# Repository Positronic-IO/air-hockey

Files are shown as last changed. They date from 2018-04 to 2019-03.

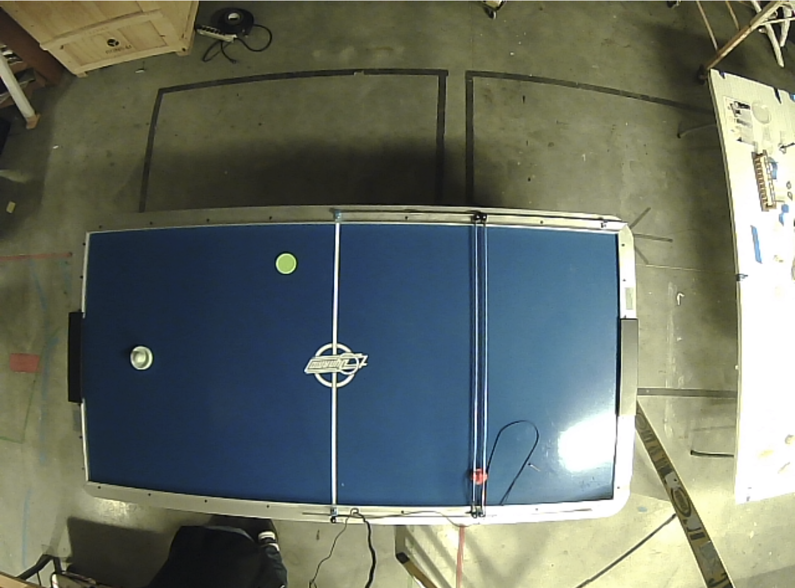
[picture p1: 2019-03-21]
notebooks/overhead-science.png

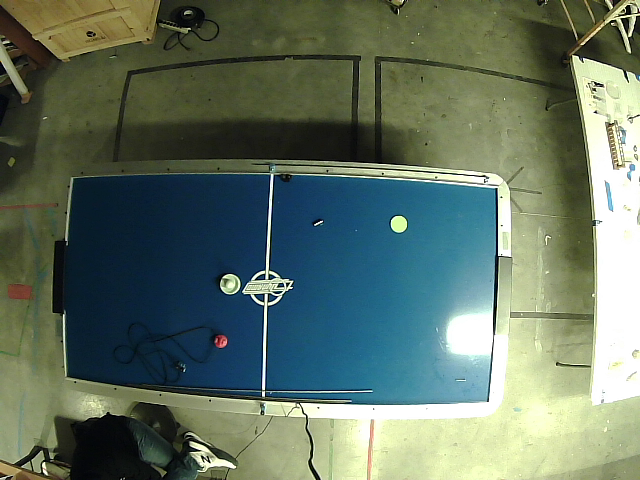
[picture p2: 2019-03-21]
notebooks/overhead-science-2.png

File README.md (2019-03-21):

# Air Hockey Vision and Robot Interface

## Introduction

In our goal to create an AI powered air hockey opponent, we have developed a vision system, state machine, and robot interface so that the robot can play in real time against a human opponent.

## Prerequisites

First, you will need to install all necessary dependencies.

### Python dependencies

Run `pip3 install pipenv`. `pipenv` is used for Python package management. 

Once downloaded, run `pipenv install`. This will create a virtual environment for our application and will install the dependencies from the `Pipfile.lock` file. If this is not present, it will default to the `Pipfile` file.

### YOLO and Darknet dependencies

We use YOLO2 and Darknet for the vision system. You will need to install `CUDA 9.0` and `cuDNN 7.0`. I would follow this [tutorial](https://medium.com/@zhanwenchen/install-cuda-and-cudnn-for-tensorflow-gpu-on-ubuntu-79306e4ac04e) to set this up on your machine.

### Install Redis

You can either install redis via Docker or `apt-get`. It is up to your preference.

## Calibration and get up and running.

There are a few steps you have to do to sync up the camera footage with the robot.

The html canvas and robot sets the origin point at the top left corner. However, the top left corner of the table in the footage is not the origin. Thus, you will need to compute the offset necessary to translate the frames up and left so that the top left corner of the table in the footage is the origin point.

It does not matter if Redis has already been started or not.

_Make sure you are in your virtual environment. Run `pipenv shell` to initiate you environment if you are not already in it._

1. Grab a image from the source where your bot will be playing. This will be used to determine its location and dimensions.
2. Run `python calibrate_offset.py --file <Your Image>`. This will grab the necessary information and publish it to redis to be used for later.
3. In `retrieve_state.py`, set your defaults. The table dimensions either user-defined. Other defaults are dependent on your table and specifications. Please play with these.
4. Run `retrieve_state.py`. This will we retrieve the state of the entire application. It will also compute where the robot should move to. All puck/bot physics or AI should be defined in the `meet_the_puck` function.
5. In the `./simulator`, edit the `index.html` canvas components `width` and `height` attributes. Set these to the table dimensions.
6. In the same directory, run `npm start` to start simulator. Open `http://localhost:3000` to see where the puck and bot is on the table.
7. Run `python yolo/table.py` to start recording the state of the game from the YOLO2/Darknet neural net.

#### Author

Positronic Ai - Visit us at our [website](https://positronic.ai)!

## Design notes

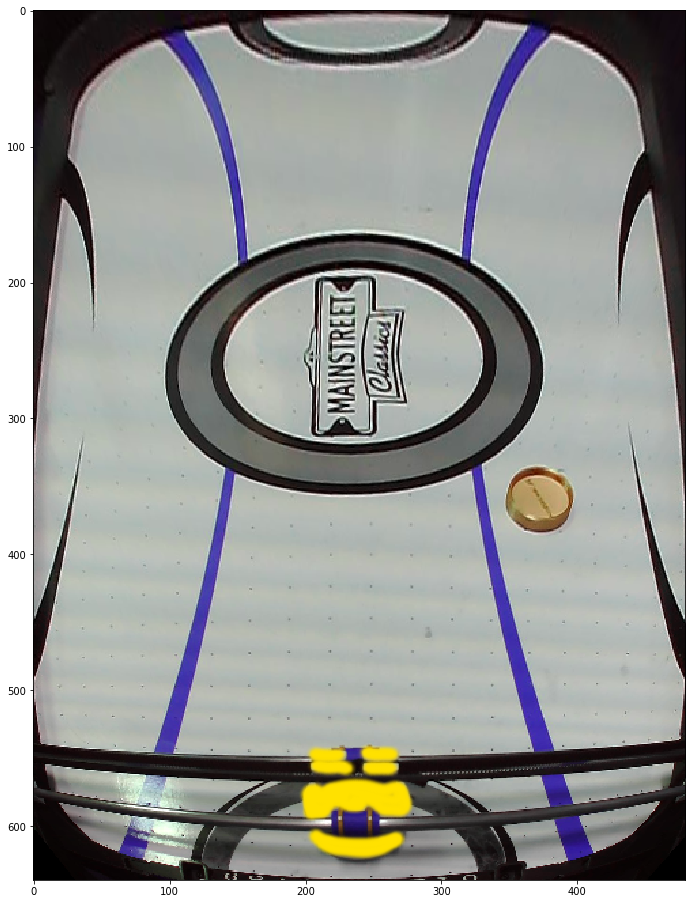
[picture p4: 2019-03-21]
notebooks/homography/homography_4_yellowbot.png

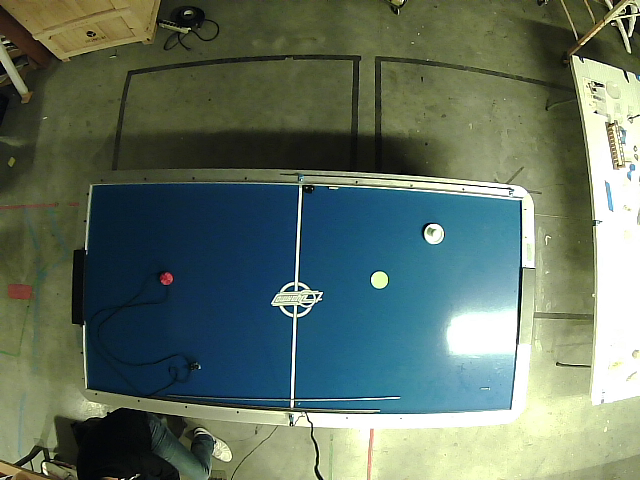
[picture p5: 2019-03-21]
notebooks/overhead-science-4.png

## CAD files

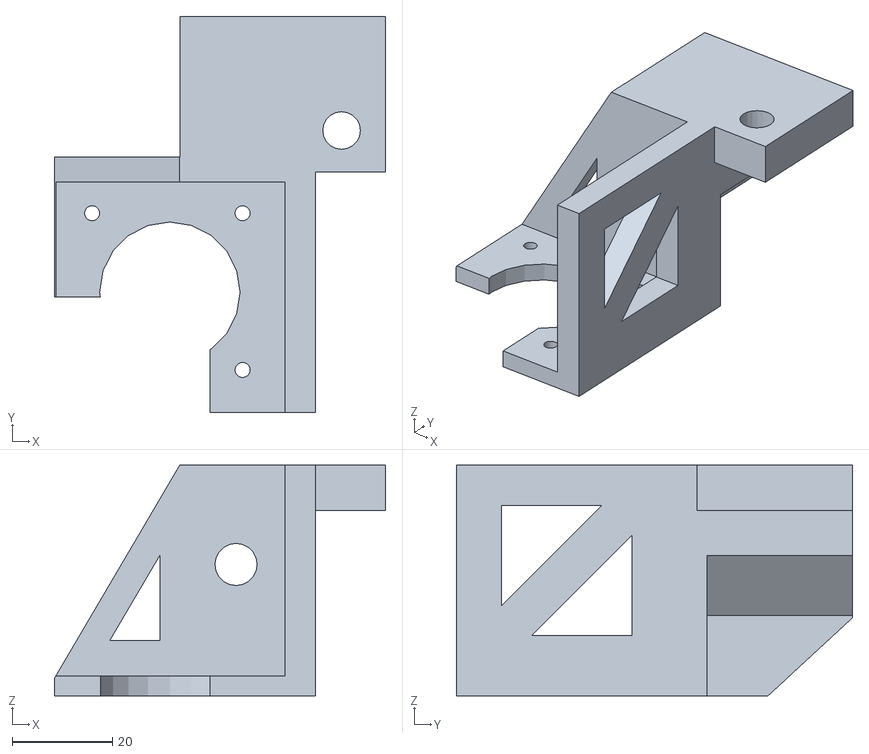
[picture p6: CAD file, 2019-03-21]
3DParts/Big table little motor mounts.stl
66.0 x 79.0 x 46.0

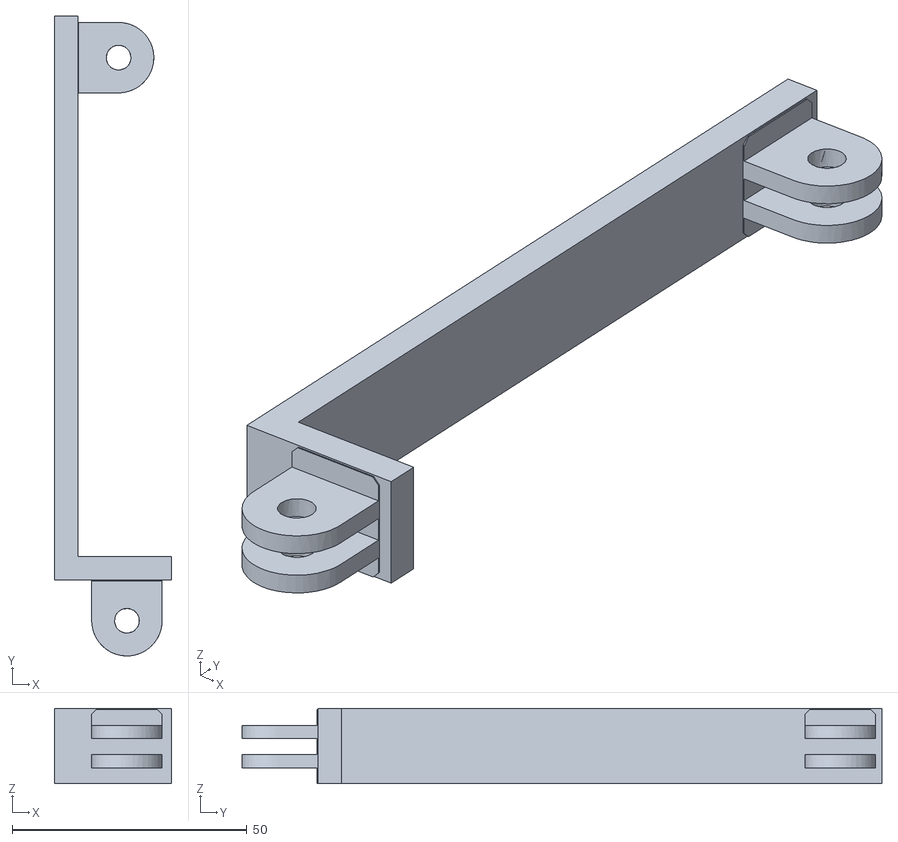
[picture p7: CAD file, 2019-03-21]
3DParts/ahr_camera_mount_arm_2.stl
25.0 x 136.2 x 16.0

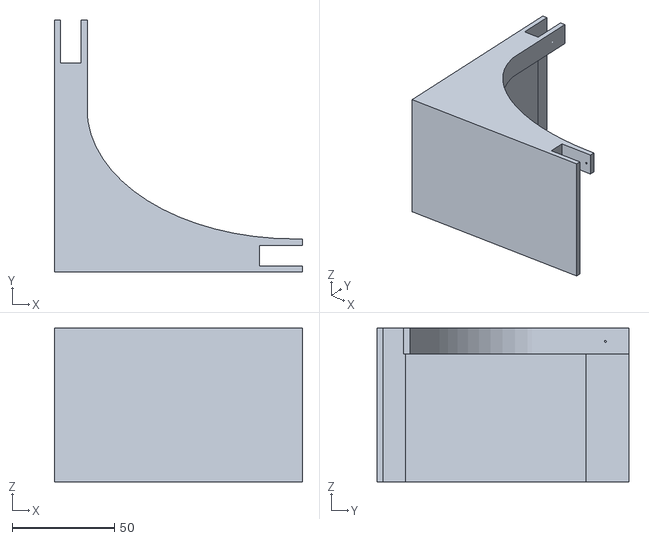
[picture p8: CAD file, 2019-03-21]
3DParts/corner_bot_left.stl
121.0 x 123.0 x 75.0

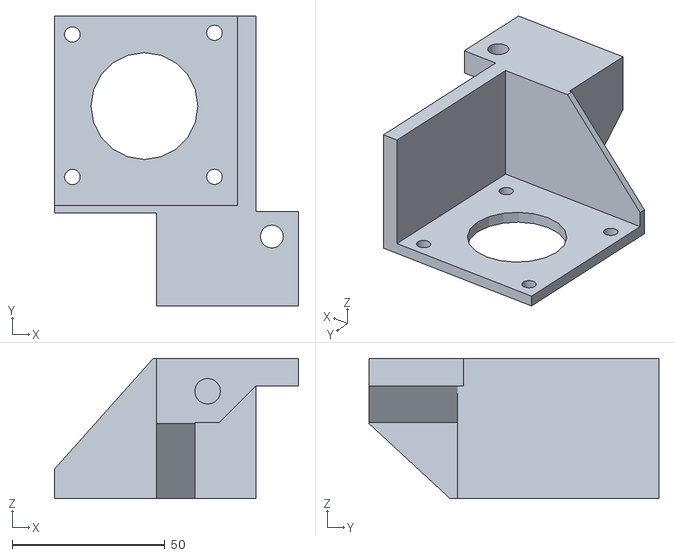
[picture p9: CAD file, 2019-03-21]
3DParts/Big table big motor mounts.stl
80.0 x 95.0 x 46.0

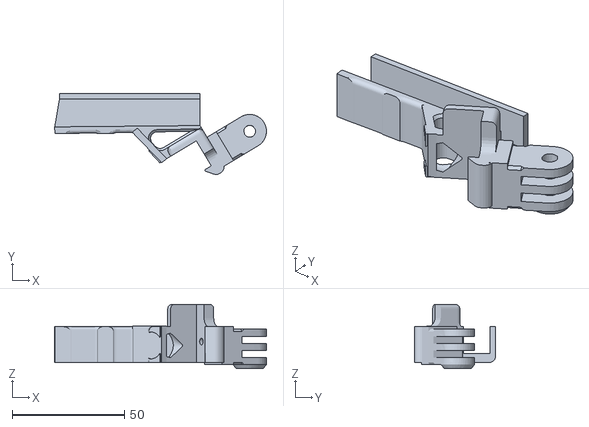
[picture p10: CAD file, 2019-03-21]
3DParts/camera-pole-mount.stl
94.6 x 36.2 x 28.7

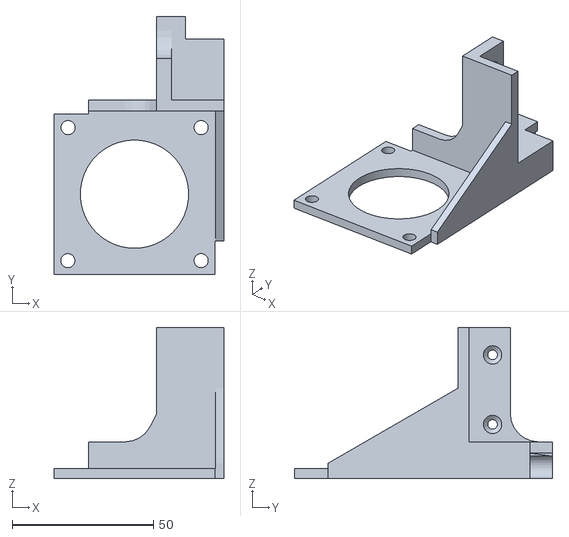
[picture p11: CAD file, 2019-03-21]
3DParts/motor_mount_right.stl
60.1 x 91.3 x 53.5

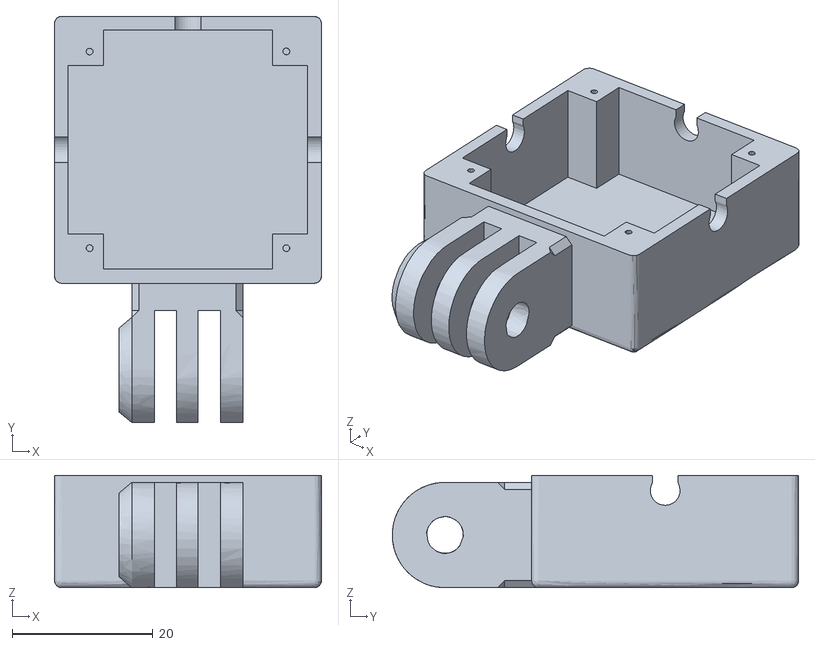
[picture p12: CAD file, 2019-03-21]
3DParts/ahr_camera_tray.stl
38.0 x 57.8 x 16.0

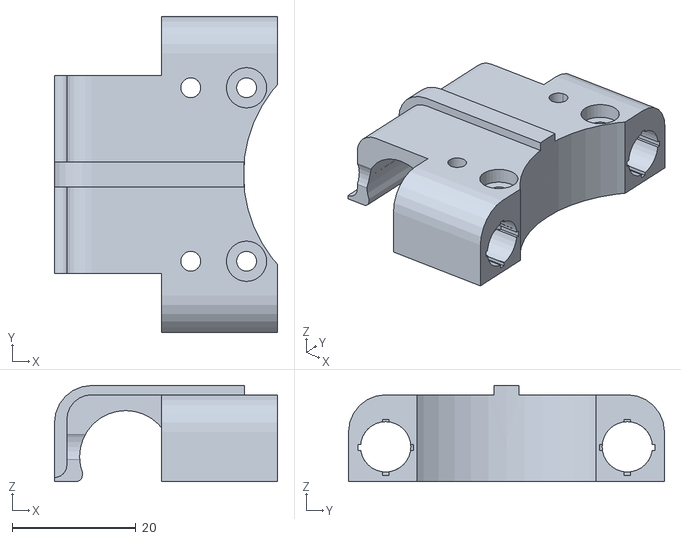
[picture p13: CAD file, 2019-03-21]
3DParts/LATERAL_SLIDER.stl
36.0 x 51.0 x 15.5

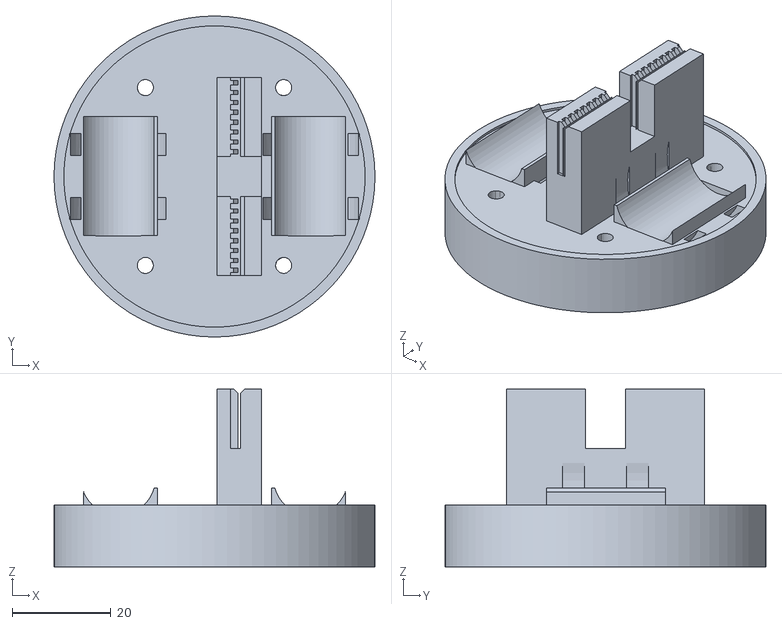
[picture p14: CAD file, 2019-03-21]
3DParts/ahr_bot_top.stl
65.0 x 65.0 x 36.0

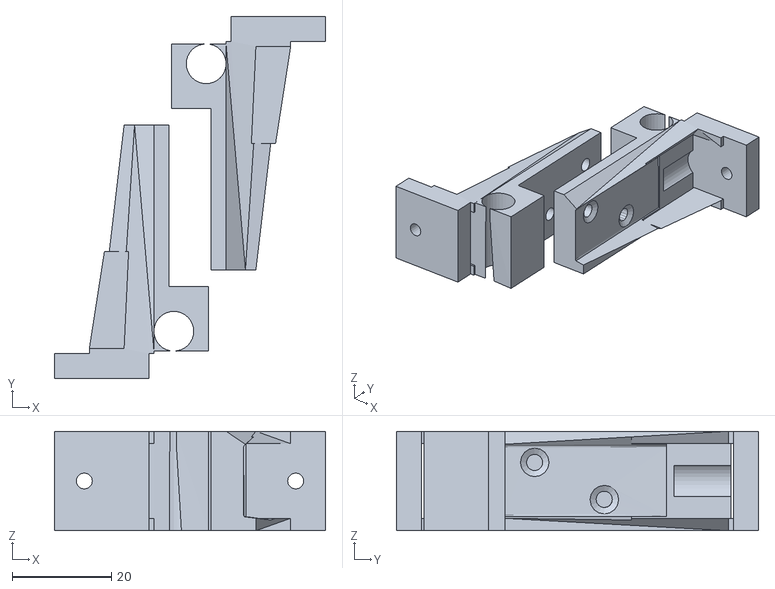
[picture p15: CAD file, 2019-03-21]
3DParts/lateral_support.stl
54.5 x 72.8 x 20.0

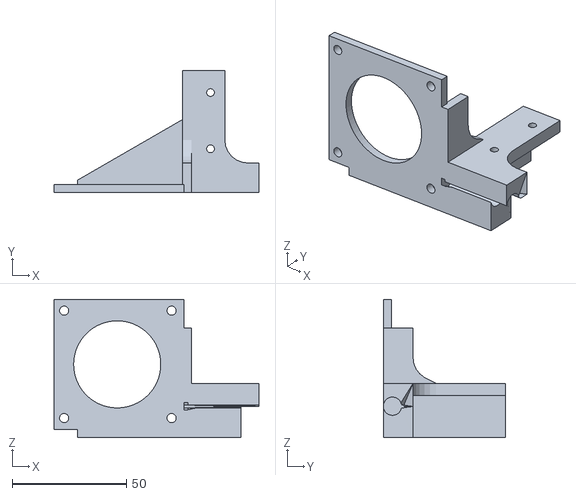
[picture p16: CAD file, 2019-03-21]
3DParts/motor_mount_left.stl
89.7 x 53.5 x 60.5

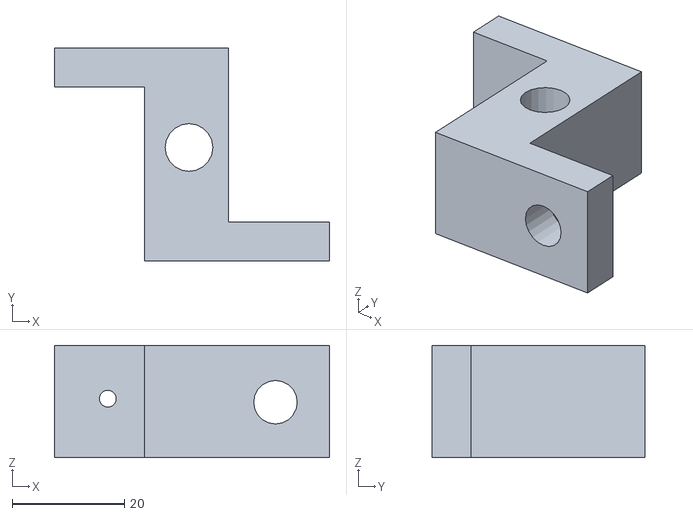
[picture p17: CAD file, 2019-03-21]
3DParts/Rail Mounts.stl
49.0 x 38.0 x 20.0

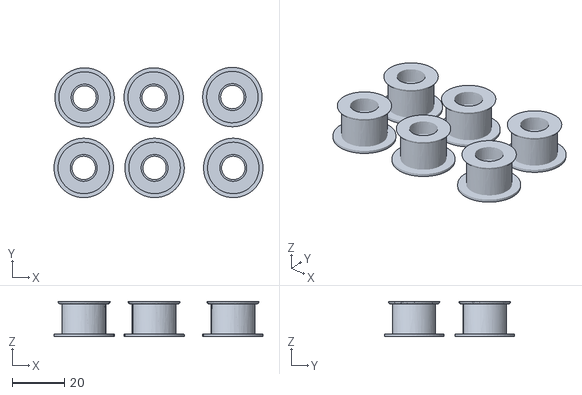
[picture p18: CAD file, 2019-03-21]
3DParts/pulley.stl
79.7 x 49.7 x 13.4

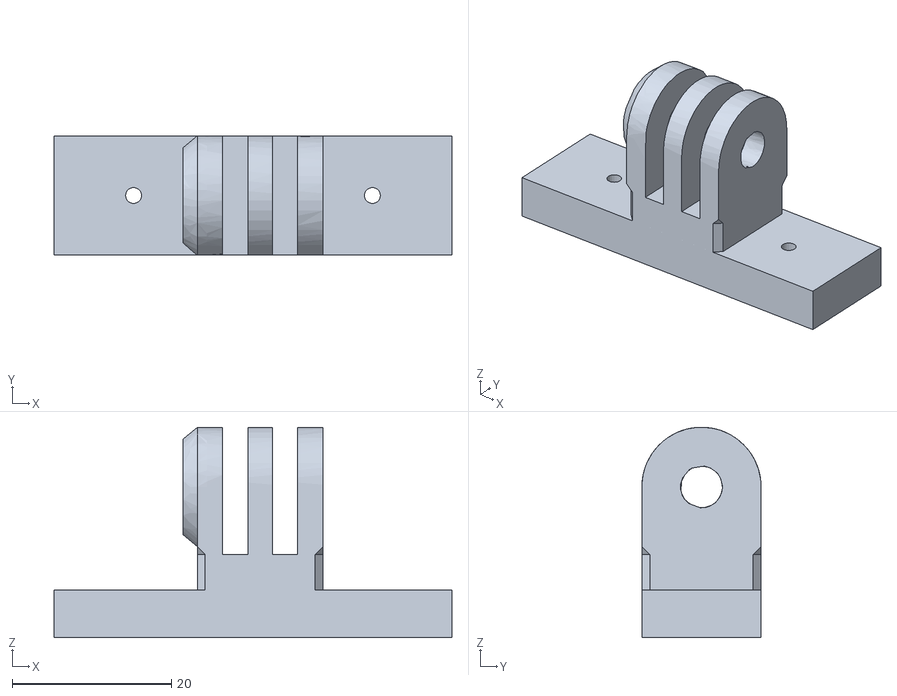
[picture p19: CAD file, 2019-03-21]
3DParts/ahr_camera_mount_base.stl
50.0 x 15.0 x 26.4

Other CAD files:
3DParts/Big table motor mount.stl
3DParts/bushings.stl
3DParts/corner_bot_right.stl
3DParts/Lateral Slider.stl
3DParts/ahr_camera_mount_arm_2 (1).stl

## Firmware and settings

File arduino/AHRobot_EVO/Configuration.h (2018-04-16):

// POSITRONIC FLUFFY GARBANZO - AIR HOCKEY ROBOT

// USER CONFIGURATIONS HERE
// ROBOT DIMENSIONS, MAX SPEED, MAX ACCELERATION, CALIBRATION...

//#define DEBUG

// ABSOLUTE MAX ROBOT SPEED AND ACCELERATION
// THIS VALUES DEPENDS ON YOUR ROBOT CONSTRUCTION (MOTORS, MECHANICS...)
// RECOMMENDED VALUES FOR 12V POWER SUPPLY
#define MAX_ACCEL 280           // Maximun motor acceleration in (steps/seg2)/1000. Max recommended value:280
#define MAX_SPEED 32767         // Maximun speed in steps/seg. Max absolute value: 32767!!

#define MIN_ACCEL 100
#define MIN_SPEED 5000
#define SCURVE_LOW_SPEED 2500
#define SCURVE_HIGH_SPEED 28000

// Geometric calibration.
// This depends on the pulley teeth. DEFAULT: 200(steps/rev)*8(microstepping) = 1600 steps/rev. 1600/32teeth*2mm(GT2) = 25 steps/mm
#define X_AXIS_STEPS_PER_UNIT 25    
#define Y_AXIS_STEPS_PER_UNIT 25

// This is the center of the table. All units in milimeters
// This are the dimensions of the official air hockey table Exploter from Buffalo
#define TABLE_LENGTH 860.425
#define TABLE_WIDTH 482.6
#define ROBOT_CENTER_X TABLE_WIDTH/2   // Center of robot.
#define ROBOT_CENTER_Y TABLE_LENGTH/2

// Absolute Min and Max robot positions in mm (measured from center of robot pusher)
#define ROBOT_MIN_X 60
#define ROBOT_MIN_Y 58
#define ROBOT_MAX_X TABLE_WIDTH-ROBOT_MIN_X
#define ROBOT_MAX_Y ROBOT_CENTER_Y-60

// PuckSize (puck radio in mm)
#define PUCK_SIZE 22

// Initial robot position in mm
// The robot must be at this position at start time
// Default: Centered in X and minimun position in Y
#define ROBOT_INITIAL_POSITION_X TABLE_WIDTH/2
#define ROBOT_INITIAL_POSITION_Y 58   // Measured from center of the robot pusher to the table border

// Robot defense and attack lines
#define ROBOT_DEFENSE_POSITION_DEFAULT 72
#define ROBOT_DEFENSE_ATTACK_POSITION_DEFAULT 280
#define ROBOT_DEFENSE_POSITION_MIN 60
#define ROBOT_DEFENSE_POSITION_MAX 100
#define ROBOT_DEFENSE_ATTACK_POSITION_MIN 140
#define ROBOT_DEFENSE_ATTACK_POSITION_MAX 360

// CORRECTION FOR VISION SYSTEM LAG
#define VISION_SYSTEM_LAG 60   // in miliseconds

// CORRECTION OF MISSING STEPS ON MOTORS
// Coment this lines if you don´t want to make the corrections
#define CORRECT_MISSING_STEPS 1
#define MISSING_STEPS_MAX_ERROR_X 5
#define MISSING_STEPS_MAX_ERROR_Y 5
#define ROBOT_POSITION_CAMERA_CORRECTION_Y 0 // Correction of the position of the camera because the camera point of view and mark position

// PACKET SIZE (UDP MESSAGE)
#define PACKET_SIZE 12  // UDP PACKET SIZE (without sync mark), total size = PACKET_SIZE+3(sync mark)

// Utils (don´t modify)
#define CLR(x,y) (x&=(~(1<<y)))
#define SET(x,y) (x|=(1<<y))

#define RAD2GRAD 57.2957795
#define GRAD2RAD 0.01745329251994329576923690768489

#define ZERO_SPEED 65535

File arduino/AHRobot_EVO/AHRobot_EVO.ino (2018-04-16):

// POSITRONIC FLUFFY GARBANZO - AIR HOCKEY ROBOT
// Author: POSITRONIC AI
// Hardware: Arduino Leonardo + JJROBOTS brain shield v3 (devia)
// Version: 2.0
// Project page :
//   TODO
// GIT repository:
//   https://github.com/Positronic-IO/fluffy-garbanzo

#define VERSION "2.0"

// ROBOT and USER configuration parameters
#include "Configuration.h"
#include "Definitions.h"   // Variable definitions

void setup()
{
  // STEPPER PINS ON JJROBOTS BRAIN SHIELD
  pinMode(4, OUTPUT); // ENABLE MOTORS
  pinMode(7, OUTPUT); // STEP MOTOR 1 PORTE,6
  pinMode(8, OUTPUT); // DIR MOTOR 1  PORTB,4
  pinMode(12, OUTPUT); // STEP MOTOR 2 PORTD,6
  pinMode(5, OUTPUT); // DIR MOTOR 2  PORTC,6
  digitalWrite(4, HIGH);  // Disbale stepper motors

  pinMode(10, OUTPUT);  // Servo1 (arm)
  pinMode(13, OUTPUT);  // Servo2

  pinMode(A4, OUTPUT);  // Microstepping selector
  digitalWrite(A4, LOW); // 1/8 Microstepping

  pinMode(A3,INPUT);   // User puch button (pushed=>gnd)
  digitalWrite(A3,HIGH); // Enable pullup

  Serial.begin(115200);   // PC debug connection
  Serial1.begin(115200);  // ESP serial connection
  delay(5000);
  Serial.print("Positronic Fluffy Garbanzo: Air Hockey Robot: Version ");
  Serial.println(VERSION);
  delay(1000);

  //LED blink
  for (uint8_t k = 0; k < 5; k++)
  {
    digitalWrite(13, HIGH);
    delay(300);
    digitalWrite(13, LOW);
    delay(300);
  }

  Serial.println("Initializing Wifi module...");
  // ESP Wifi module initialization routine.
  // The Robot will generate it´s own wifi network JJROBOTS_xx and listen external UDP messages...
  ESPInit();

  Serial.println("Initializing Stepper motors...");
  // STEPPER MOTORS INITIALIZATION
  // We use TIMER 1 for stepper motor 1 and Timer 3 for motor 2
  // TIMER1 CTC MODE
  TCCR1B &= ~(1 << WGM13);
  TCCR1B |=  (1 << WGM12);
  TCCR1A &= ~(1 << WGM11);
  TCCR1A &= ~(1 << WGM10);

  // output mode = 00 (disconnected)
  TCCR1A &= ~(3 << COM1A0);
  TCCR1A &= ~(3 << COM1B0);

  // Set the timer pre-scaler
  // Generally we use a divider of 8, resulting in a 2MHz timer on 16MHz CPU
  TCCR1B = (TCCR1B & ~(0x07 << CS10)) | (2 << CS10);

  OCR1A = ZERO_SPEED;   // Motor stopped
  dir_M1 = 0;
  TCNT1 = 0;

  // We use TIMER 3 for stepper motor 2
  // STEPPER MOTORS INITIALIZATION
  // TIMER3 CTC MODE
  TCCR3B &= ~(1 << WGM13);
  TCCR3B |=  (1 << WGM12);
  TCCR3A &= ~(1 << WGM11);
  TCCR3A &= ~(1 << WGM10);

  // output mode = 00 (disconnected)
  TCCR3A &= ~(3 << COM1A0);
  TCCR3A &= ~(3 << COM1B0);

  // Set the timer pre-scaler
  // Generally we use a divider of 8, resulting in a 2MHz timer on 16MHz CPU
  TCCR3B = (TCCR3B & ~(0x07 << CS10)) | (2 << CS10);

  OCR3A = ZERO_SPEED;   // Motor stopped
  dir_M2 = 0;
  TCNT3 = 0;

  delay(1000);
  TIMSK1 |= (1 << OCIE1A); // Enable Timer1 interrupt
  TIMSK3 |= (1 << OCIE1A); // Enable Timer1 interrupt

  // Enable steppers
  digitalWrite(4, LOW);

  delay(1000);

  //Initializing Robot initial position and parameters...
  position_M1 = (ROBOT_INITIAL_POSITION_X + ROBOT_INITIAL_POSITION_Y) * X_AXIS_STEPS_PER_UNIT;
  position_M2 = (ROBOT_INITIAL_POSITION_X - ROBOT_INITIAL_POSITION_Y) * Y_AXIS_STEPS_PER_UNIT;
  target_position_M1 = position_M1;
  target_position_M2 = position_M2;

  user_max_speed = MAX_SPEED;
  user_max_accel = MAX_ACCEL;
  max_acceleration = user_max_accel;
  max_speed = user_max_speed / 2;
  user_robot_defense_position = ROBOT_DEFENSE_POSITION_DEFAULT;
  user_robot_defense_attack_position = ROBOT_DEFENSE_ATTACK_POSITION_DEFAULT;
  defense_position = ROBOT_DEFENSE_POSITION_DEFAULT;   // Robot y axis defense position
  attack_position = ROBOT_DEFENSE_ATTACK_POSITION_DEFAULT;   // Robot y axis position for defense+attack

  // Output parameters to console
  Serial.print("Max_acceleration: ");
  Serial.println(user_max_accel);
  Serial.print("Max speed: ");
  Serial.println(user_max_speed);
  Serial.println("Moving to initial position...");
  Serial.println("Ready!!");

  setPosition_straight(0, 3, 0, 0);

  digitalWrite(13, HIGH);
  Serial.print("Positronic Fluffy Garbanzo: Air Hockey Robot: Version ");
  Serial.println(VERSION);
  Serial.println("ready...");

  testmode=false;
  robot_status = 0;
  timer_old = micros();
  timer_packet_old = timer_old;
  micros_old = timer_old;
}

// Main loop
void loop()
{
  int dt;
  uint8_t logOutput = 0;

  debug_counter++;

  if (analogRead(A3)<100) // pushbutton pushed => TEST PATTERN
  {
    loop_counter=0;
    testmode=true;
  }
  
  timer_value = micros();
  if ((timer_value - timer_old) >= 1000) // MAIN 1Khz loop
  {
    timer_old = timer_value;
    loop_counter++;

    packetRead();  // Check for new packets...
    if (newPacket > 0)
    {
      dt = (timer_value - timer_packet_old) / 1000.0;
      //Serial.println(dt);
      //dt = 16;  //60 Hz = 16.66ms
      timer_packet_old = timer_value;
      logOutput = 0;

      Serial.println();
      Serial.print("Packet-");
      Serial.print(newPacket);
      Serial.println();

      if (newPacket == 2) { // User sends a manual move
        robot_status = 5;    // Manual mode
        Serial.print(" ");
        Serial.print(user_target_x);
        Serial.print(",");
        Serial.print(user_target_y);
      }

      robotStrategy();
      Serial.println();
      newPacket = 0;
    }  // End packet received

    if (testmode)
      testMovements();

    if ((loop_counter % 10) == 0)
      updatePosition_straight();  // update straight line motion algorithm

    // Position, speed and acceleration control:
    positionControl();
  } // 1Khz loop
}

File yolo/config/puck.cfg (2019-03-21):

[net]
batch=64
subdivisions=16
height=480
width=640
channels=3
momentum=0.9
decay=0.0005
angle=0
saturation = 1.5
exposure = 1.5
hue=.1

learning_rate=0.0001
max_batches = 45000
policy=steps
steps=100,25000,35000
scales=10,.1,.1

[convolutional]
batch_normalize=1
filters=32
size=3
stride=1
pad=1
activation=leaky

[maxpool]
size=2
stride=2

[convolutional]
batch_normalize=1
filters=64
size=3
stride=1
pad=1
activation=leaky

[maxpool]
size=2
stride=2

[convolutional]
batch_normalize=1
filters=128
size=3
stride=1
pad=1
activation=leaky

[convolutional]
batch_normalize=1
filters=64
size=1
stride=1
pad=1
activation=leaky

[convolutional]
batch_normalize=1
filters=128
size=3
stride=1
pad=1
activation=leaky

[maxpool]
size=2
stride=2

[convolutional]
batch_normalize=1
filters=256
size=3
stride=1
pad=1
activation=leaky

[convolutional]
batch_normalize=1
filters=128
size=1
stride=1
pad=1
activation=leaky

[convolutional]
batch_normalize=1
filters=256
size=3
stride=1
pad=1
activation=leaky

[maxpool]
size=2
stride=2

[convolutional]
batch_normalize=1
filters=512
size=3
stride=1
pad=1
activation=leaky

[convolutional]
batch_normalize=1
filters=256
size=1
stride=1
pad=1
activation=leaky

[convolutional]
batch_normalize=1
filters=512
size=3
stride=1
pad=1
activation=leaky

[convolutional]
batch_normalize=1
filters=256
size=1
stride=1
pad=1
activation=leaky

[convolutional]
batch_normalize=1
filters=512
size=3
stride=1
pad=1
activation=leaky

[maxpool]
size=2
stride=2

[convolutional]
batch_normalize=1
filters=1024
size=3
stride=1
pad=1
activation=leaky

[convolutional]
batch_normalize=1
filters=512
size=1
stride=1
pad=1
activation=leaky

[convolutional]
batch_normalize=1
filters=1024
size=3
stride=1
pad=1
activation=leaky

[convolutional]
batch_normalize=1
filters=512
size=1
stride=1
pad=1
activation=leaky

[convolutional]
batch_normalize=1
filters=1024
size=3
stride=1
pad=1
activation=leaky


#######

[convolutional]
batch_normalize=1
size=3
stride=1
pad=1
filters=1024
activation=leaky

[convolutional]
batch_normalize=1
size=3
stride=1
pad=1
filters=1024
activation=leaky

[route]
layers=-9

[reorg]
stride=2

[route]
layers=-1,-3

[convolutional]
batch_normalize=1
size=3
stride=1
pad=1
filters=1024
activation=leaky

[convolutional]
size=1
stride=1
pad=1
filters=30
activation=linear

[region]
anchors = 1.08,1.19,  3.42,4.41,  6.63,11.38,  9.42,5.11,  16.62,10.52
bias_match=1
classes=1
coords=4
num=5
softmax=1
jitter=.2
rescore=1

object_scale=5
noobject_scale=1
class_scale=1
coord_scale=1

absolute=1
thresh = .6
random=0

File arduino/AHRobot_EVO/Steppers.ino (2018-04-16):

// POSITRONIC FLUFFY GARBANZO - AIR HOCKEY ROBOT
// STEPPERS MOTOR CONTROL
// Updated: Now it supports DRV8825 drivers and A4988 drivers
// SPEED, ACCELERATION AND POSITION CONTROL using Arduino 16 bit Timer interrupts
// We control the speed of the motors with interrupts (Timer1 and Timer3). tested up to 32Khz.
// The position of the motor is controlled at 1Khz (in the main loop)

// TIMER 1 : STEPPER MOTOR SPEED CONTROL MOTOR1
ISR(TIMER1_COMPA_vect)
{
  if (dir_M1 == 0)
    return;

  SET(PORTE, 6); // STEP X-AXIS (MOTOR1)
  position_M1 += dir_M1;
  __asm__ __volatile__ (
    "nop" "\n\t"
    "nop" "\n\t"
    "nop" "\n\t"
    "nop" "\n\t"
    "nop" "\n\t"
    "nop" "\n\t"
    "nop" "\n\t"
    "nop" "\n\t"
    "nop" "\n\t"
    "nop" "\n\t"
    "nop" "\n\t"
    "nop");  // Wait for step pulse
  CLR(PORTE, 6);
}

// TIMER 3 : STEPPER MOTOR SPEED CONTROL MOTOR2
ISR(TIMER3_COMPA_vect)
{
  if (dir_M2 == 0)
    return;

  SET(PORTD, 6); // STEP Y-AXIS (Motor2)
  position_M2 += dir_M2;
  __asm__ __volatile__ (
    "nop" "\n\t"
    "nop" "\n\t"
    "nop" "\n\t"
    "nop" "\n\t"
    "nop" "\n\t"
    "nop" "\n\t"
    "nop" "\n\t"
    "nop" "\n\t"
    "nop" "\n\t"
    "nop");  // Wait for step pulse
  CLR(PORTD, 6);
}

// POSITION CONTROL
// We use a ramp for acceleration and deceleration
// To calculate the point we should start to decelerate we use this formula:
// stop_position = actual_posicion + (actual_speed*actual_speed)/(2*max_deceleration)
// Input parameters:
//    target_position_M1
//    target_speed_M1
//    max_acceleration
void positionControl()
{
  int32_t temp;
  uint32_t timer;
  int16_t dt;
  int16_t result_speed_M1, result_speed_M2;
  int16_t absSpeedM1, absSpeedM2;


  real_position_x = ((position_M1 + position_M2) / 2) / X_AXIS_STEPS_PER_UNIT;
  real_position_y = ((position_M1 - position_M2) / 2) / Y_AXIS_STEPS_PER_UNIT;
  //SET(PORTF,3); // for external timing debug
  timer = micros();
  // dt = delta time in microseconds...
  dt = constrain(timer - micros_old, 0, 2000); // Limit dt (it should be around 1000 most times, 1ms)
  //Serial.println(dt);
  micros_old = timer;

  // Movement accelerations...
  acceleration_M1 = max_acceleration;
  acceleration_M2 = max_acceleration;

  // Scurve profile implementation...
  absSpeedM1 = abs(speed_M1);
  absSpeedM2 = abs(speed_M2);
  if (absSpeedM1 < SCURVE_LOW_SPEED) {
    acceleration_M1 = map(absSpeedM1, 0, SCURVE_LOW_SPEED, MIN_ACCEL, max_acceleration);
    if (acceleration_M1 > max_acceleration)
      acceleration_M1 = max_acceleration;
  }
  if (absSpeedM2 < SCURVE_LOW_SPEED) {
    acceleration_M2 = map(absSpeedM2, 0, SCURVE_LOW_SPEED, MIN_ACCEL, max_acceleration);
    if (acceleration_M2 > max_acceleration)
      acceleration_M2 = max_acceleration;
  }
  // SCURVE FACOR 1900!!!

  // MOTOR1 M1
  temp = (long)speed_M1 * speed_M1;
  temp = temp / (1900 * (long)acceleration_M1);
  pos_stop_M1 = position_M1 + sign(speed_M1) * temp;    // We calculate the stop position if we apply a deceleration right now.
  if (target_position_M1 > position_M1)    // Positive move
  {
    if (pos_stop_M1 >= target_position_M1)  // Do we need to start stopping?
      result_speed_M1 = 0;                    // The deceleration ramp is done inside the setSpeed function
    else
      result_speed_M1 = target_speed_M1;      // The aceleration ramp is done inside the setSpeed function
  }
  else   // Negative move
  {
    if (pos_stop_M1 <= target_position_M1)  // Start decelerating?
      result_speed_M1 = 0;
    else
      result_speed_M1 = -target_speed_M1;
  }

  // MOTOR2 M2
  temp = (long)speed_M2 * speed_M2;
  temp = temp / (1900 * (long)acceleration_M2);
  pos_stop_M2 = position_M2 + sign(speed_M2) * temp;
  if (target_position_M2 > position_M2) // Positive move
  {
    if (pos_stop_M2 >= target_position_M2)  // Start decelerating?
      result_speed_M2 = 0;                  // The deceleration ramp is done inside the setSpeed function
    else
      result_speed_M2 = target_speed_M2;    // The aceleration ramp is done inside the setSpeed function
  }
  else   // Negative move
  {
    if (pos_stop_M2 <= target_position_M2)  // Start decelerating?
      result_speed_M2 = 0;
    else
      result_speed_M2 = -target_speed_M2;
  }

  setMotorSpeed(result_speed_M1, result_speed_M2, dt); // change Motors speed
  //CLR(PORTF,3); // for external timing debug
}

// Speed could be positive or negative
void setMotorSpeed(int16_t m1tspeed, int16_t m2tspeed, int16_t dt)
{
  long timer_period;
  int16_t accel;

  // Limit max speeds
  m1tspeed = constrain(m1tspeed, -user_max_speed, user_max_speed);
  m2tspeed = constrain(m2tspeed, -user_max_speed, user_max_speed);

  // M1 MOTOR
  // We limit acceleration => speed ramp
  accel = ((long)acceleration_M1 * dt) / 1000; // We divide by 1000 because dt are in microseconds
  if (((long)m1tspeed - speed_M1) > accel) // We use long here to avoid overflow on the operation
    speed_M1 += accel;
  else if (((long)speed_M1 - m1tspeed) > accel)
    speed_M1 -= accel;
  else
    speed_M1 = m1tspeed;

  // Check if we need to change the direction pins
  if ((speed_M1 == 0) && (dir_M1 != 0))
    dir_M1 = 0;
  else if ((speed_M1 > 0) && (dir_M1 != 1))
  {
    CLR(PORTB, 4);
    dir_M1 = 1;
  }
  else if ((speed_M1 < 0) && (dir_M1 != -1))
  {
    SET(PORTB, 4);
    dir_M1 = -1;
  }

  if (speed_M1 == 0)
    timer_period = ZERO_SPEED;
  else if (speed_M1 > 0)
    timer_period = 2000000 / speed_M1; // 2Mhz timer
  else
    timer_period = 2000000 / -speed_M1;

  if (timer_period > 65535)   // Check for minimun speed (maximun period without overflow)
    timer_period = ZERO_SPEED;

  OCR1A = timer_period;
  // Check  if we need to reset the timer...
  if (TCNT1 > OCR1A)
    TCNT1 = 0;

  // M2 MOTOR
  // We limit acceleration => speed ramp
  accel = ((long)acceleration_M2 * dt) / 1000;
  if (((long)m2tspeed - speed_M2) > accel)
    speed_M2 += accel;
  else if (((long)speed_M2 - m2tspeed) > accel)
    speed_M2 -= accel;
  else
    speed_M2 = m2tspeed;

  // Check if we need to change the direction pins
  if ((speed_M2 == 0) && (dir_M2 != 0))
    dir_M2 = 0;
  else if ((speed_M2 > 0) && (dir_M2 != 1))
  {
    CLR(PORTC, 6);
    dir_M2 = 1;
  }
  else if ((speed_M2 < 0) && (dir_M2 != -1))
  {
    SET(PORTC, 6);
    dir_M2 = -1;
  }

  if (speed_M2 == 0)
    timer_period = ZERO_SPEED;
  else if (speed_M2 > 0)
    timer_period = 2000000 / speed_M2; // 2Mhz timer
  else
    timer_period = 2000000 / -speed_M2;

  if (timer_period > 65535)   // Check for minimun speed (maximun period without overflow)
    timer_period = ZERO_SPEED;

  OCR3A = timer_period;
  // Check  if we need to reset the timer...
  if (TCNT3 > OCR3A)
    TCNT3 = 0;

}
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

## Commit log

2018-04-16 Add Arduino Code (ported/forked from jjrobots)
    [Configuration.h]
2018-04-16 Update to positronic version
    [Configuration.h]
2018-05-07 Notebook for bot driver (updates state)
2018-05-08 add image of mounted camera
2018-05-14 New vision with homograpy board detection
2018-05-14 Add functionality for detecting board inside vision loop.
2018-06-12 Add 3d parts stl files
    [LATERAL_SLIDER.stl, ahr_bot_top.stl, ahr_camera_mount_arm_2 (1).stl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]
2018-11-23 for science center
    [Big table big motor mounts.stl, Big table little motor mounts.stl, Big table motor mount.stl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]
2018-11-23 easy button
2018-11-23 Align screw holes
    [Big table big motor mounts.stl]
2018-11-23 problematic sample
2018-12-02 raise rail
    [Big table little motor mounts.stl]
2018-12-05 yolo implementation
    [yolo-puck.cfg]
2018-12-06 small puck
    [yolo-small-puck.cfg]
2018-12-06 larger batch size
    [yolo-puck.cfg]
2019-03-20 Change print statements to python 3 syntax. We are not savages here.
2019-03-20 Add yolo detector. Also, linted
    [puck.cfg, tiny.cfg, two-pucks.cfg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]
2019-03-21 Ignore captured frame
2019-03-21 Save frames of a video.
